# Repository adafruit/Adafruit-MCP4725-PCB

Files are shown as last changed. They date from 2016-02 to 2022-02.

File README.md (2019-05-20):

## Adafruit MCP4725 12-Bit DAC Breakout PCB
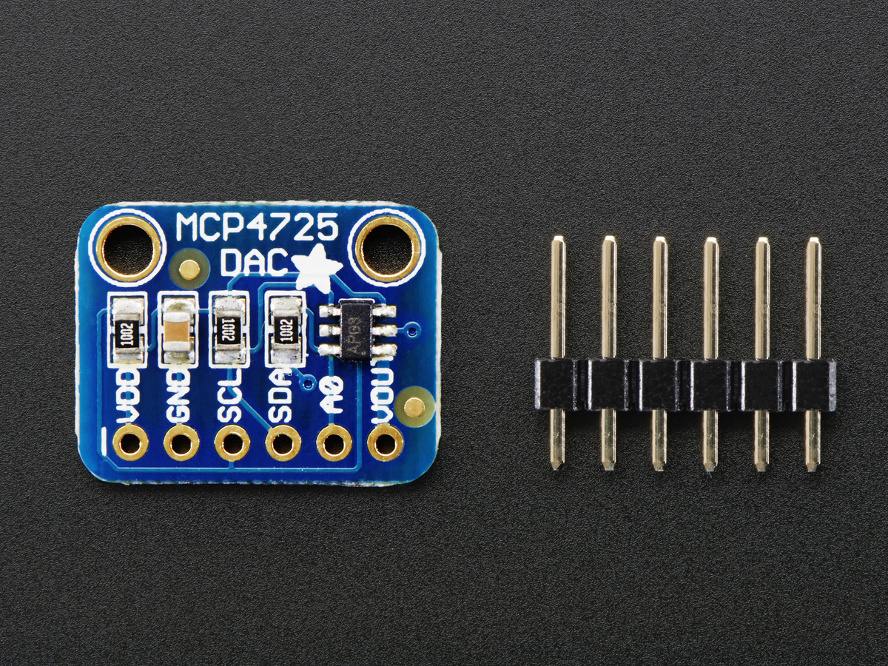
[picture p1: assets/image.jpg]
<a href="http://www.adafruit.com/products/935"><br/>
Click here to purchase one from the Adafruit shop</a>

This breakout board features the easy-to-use MCP4725 12-bit DAC. Control it via I2C and send it the value you want it to output, and the VOUT pin will have it. Great for audio / analog projects, such as when you can't use PWM but need a sine wave or adjustable bias point.

We break out the ADDR/A0 pin so you can connect two of these DACs on one I2C bus, just tie that pin of one high to keep it from conflicting. Also included is a 6-pin header, for use in a breadboard. Works with both 3.3V or 5V logic.

Some nice extras with this chip: for chips that have 3.4Mbps Fast Mode I2C (Arduino's don't) you can update the Vout at ~200 KHz. There's an EEPROM so if you write the output voltage, you can 'store it' so if the device is power cycled it will restore that voltage. The output voltage is rail-to-rail and proportional to the power pin so if you run it from 3.3V, the output range is 0-3.3V. If you run it from 5V the output range is 0-5V.

These are the Eagle CAD files for the Adafruit MCP4725 12-Bit DAC Breakout:
- https://www.adafruit.com/products/935

### License

Adafruit invests time and resources providing this open source design, please support Adafruit and open-source hardware by purchasing products from [Adafruit](https://www.adafruit.com)!

All text above must be included in any redistribution

Designed by Limor Fried/Ladyada for Adafruit Industries.
Creative Commons Attribution/Share-Alike, all text above must be included in any redistribution. 
See license.txt for additional information.

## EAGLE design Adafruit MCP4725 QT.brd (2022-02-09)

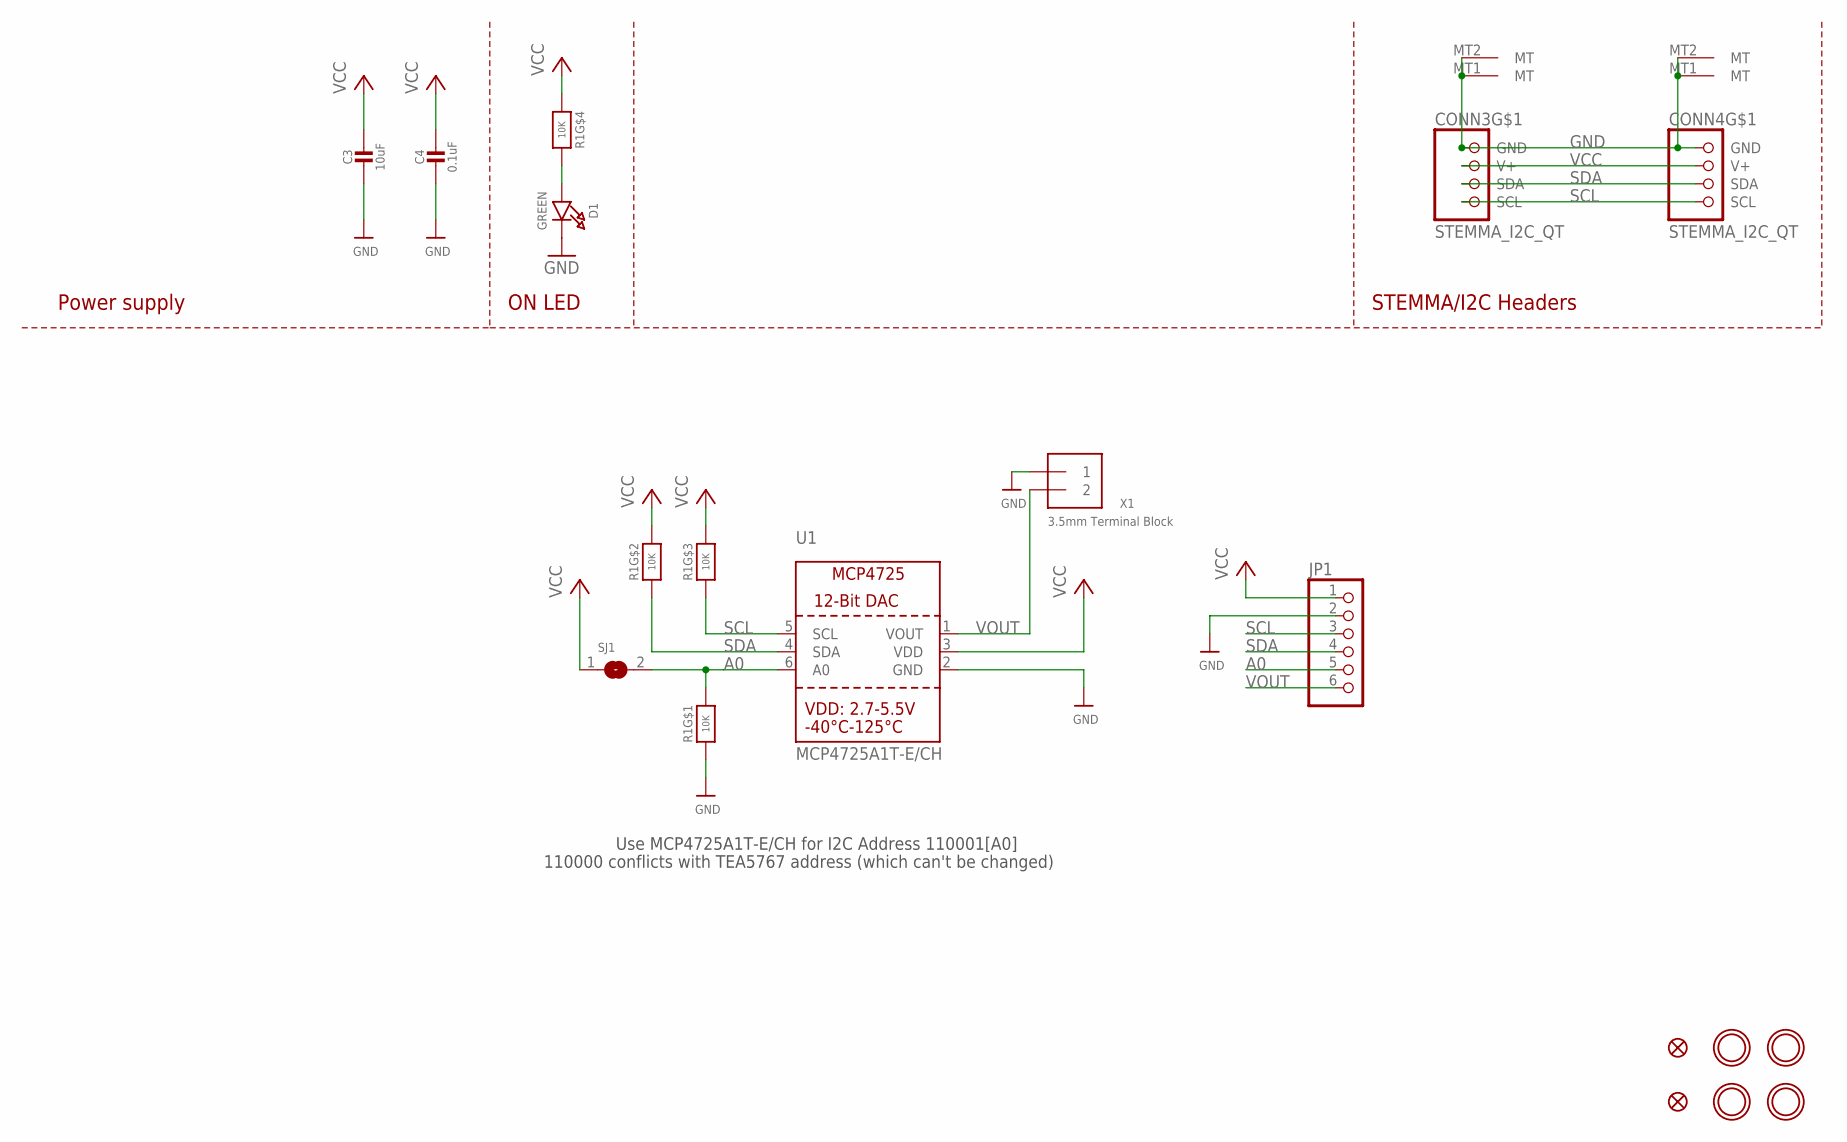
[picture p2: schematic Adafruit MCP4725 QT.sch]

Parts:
C3: 10uF; 0805-NO
C4: 0.1uF; 0603-NO
CONN3, CONN4: STEMMA_I2C_QT; JST_SH4
D1: GREEN; CHIPLED_0603_NOOUTLINE
FID3, FID4: FIDUCIAL_1MM
JP1: HEADER-1X670MIL; 1X06_ROUND_70
R1: 10K; RESPACK_4X0603
SJ1: SOLDERJUMPER; SOLDERJUMPER_ARROW_NOPASTE
U1: MCP4725A1T-E/CH; SOT23-6
U$20, U$21, U$25, U$27: MOUNTINGHOLE2.5; MOUNTINGHOLE_2.5_PLATED
X1: 3.5mm Terminal Block; TERMBLOCK_1X2-3.5MM

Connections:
A0: JP1.5, R1.8 (2), SJ1.2, U1.6 (A0)
GND: C3.2, C4.2, CONN3.1 (GND), CONN3.MT1 (MT), CONN3.MT2 (MT), CONN4.1 (GND), CONN4.MT1 (MT), CONN4.MT2 (MT), D1.C, JP1.2, R1.1, U1.2 (GND), X1.1
unnamed: D1.A, R1.5 (2)
SCL: CONN3.4 (SCL), CONN4.4 (SCL), JP1.3, R1.3 (1), U1.5 (SCL)
SDA: CONN3.3 (SDA), CONN4.3 (SDA), JP1.4, R1.2 (1), U1.4 (SDA)
VCC: C3.1, C4.1, CONN3.2 (V+), CONN4.2 (V+), JP1.1, R1.4 (1), R1.6 (2), R1.7 (2), SJ1.1, U1.3 (VDD)
VOUT: JP1.6, U1.1 (VOUT), X1.2

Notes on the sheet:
STEMMA/I2C Headers
ON LED
Power supply
Use MCP4725A1T-E/CH for I2C Address 110001[A0]
110000 conflicts with TEA5767 address (which can't be changed)

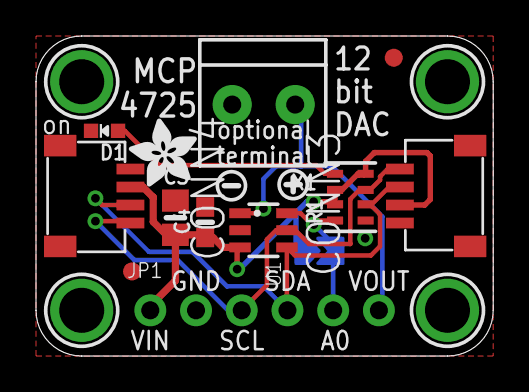
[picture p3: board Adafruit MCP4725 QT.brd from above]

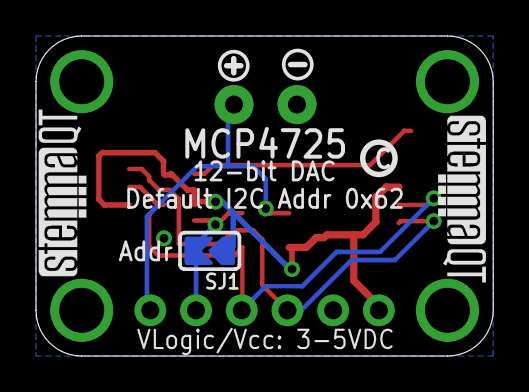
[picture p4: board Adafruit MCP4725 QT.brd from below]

Board: 2 copper layers, 25.4 x 17.8 mm, 24 parts (6 on the bottom side), 7 nets.

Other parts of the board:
U$2, U$7: SYMBOL_PLUS
U$4, U$5: SYMBOL_MINUS
U$8: PCBFEAT-REV-040
U$29: ADAFRUIT_3.5MM
U$31, U$32: STEMMAQT

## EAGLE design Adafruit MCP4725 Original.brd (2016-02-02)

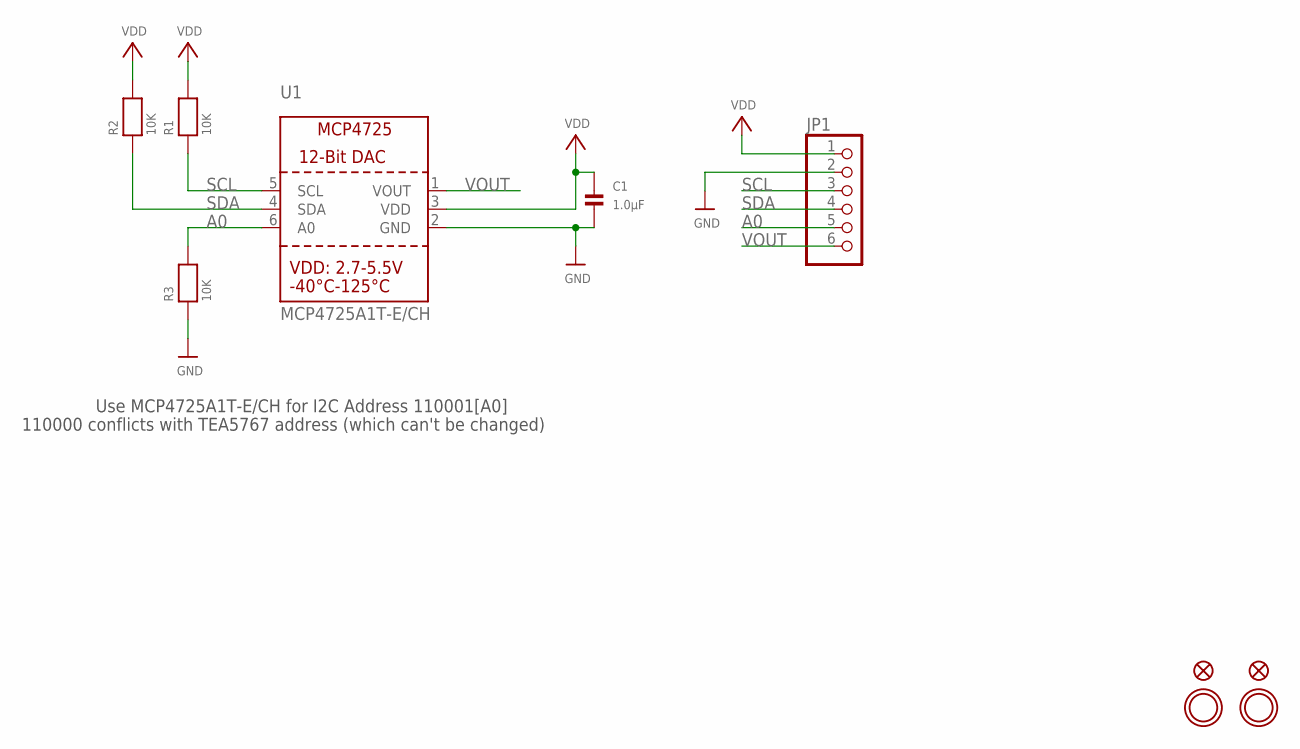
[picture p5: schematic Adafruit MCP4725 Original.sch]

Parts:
C1: 1.0µF; 0805
FID1, FID2: FIDUCIAL""; FIDUCIAL_1MM
JP1: HEADER-1X670MIL; 1X06_ROUND_70
R1, R2, R3: 10K; 0805
U1: MCP4725A1T-E/CH; SOT23-6
U$7, U$8: MOUNTINGHOLE2.5; MOUNTINGHOLE_2.5_PLATED

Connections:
A0: JP1.5, R3.2, U1.6 (A0)
GND: C1.2, JP1.2, R3.1, U1.2 (GND)
SCL: JP1.3, R1.1, U1.5 (SCL)
SDA: JP1.4, R2.1, U1.4 (SDA)
VDD: C1.1, JP1.1, R1.2, R2.2, U1.3 (VDD)
VOUT: JP1.6, U1.1 (VOUT)

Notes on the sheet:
Use MCP4725A1T-E/CH for I2C Address 110001[A0]
110000 conflicts with TEA5767 address (which can't be changed)

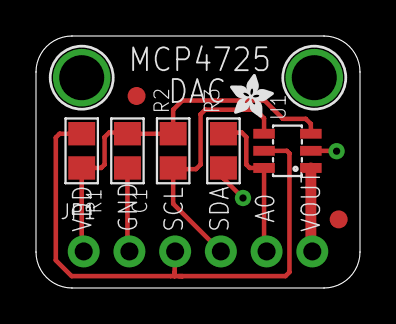
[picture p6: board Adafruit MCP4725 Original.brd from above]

Board: 2 copper layers, 18.0 x 14.0 mm, 11 parts (0 on the bottom side), 6 nets.

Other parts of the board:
U$11: ADAFRUIT_2.5MM

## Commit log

2022-02-09 Rename Adafruit MCP4725.brd to Adafruit MCP4725 Original.brd
    [Adafruit MCP4725 Original.brd]
2022-02-09 Rename Adafruit MCP4725.sch to Adafruit MCP4725 Original.sch
    [Adafruit MCP4725 Original.sch]
2022-02-09 Add QT board files.
    [Adafruit MCP4725 QT.brd, Adafruit MCP4725 QT.sch]
